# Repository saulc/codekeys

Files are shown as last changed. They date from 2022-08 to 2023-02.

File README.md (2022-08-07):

# codekeys
 arduino based mini mech keyboard

<br />This work is licensed under a <a rel="license" href="http://creativecommons.org/licenses/by-nc-sa/4.0/">Creative Commons Attribution-NonCommercial-ShareAlike 4.0 International License</a>.

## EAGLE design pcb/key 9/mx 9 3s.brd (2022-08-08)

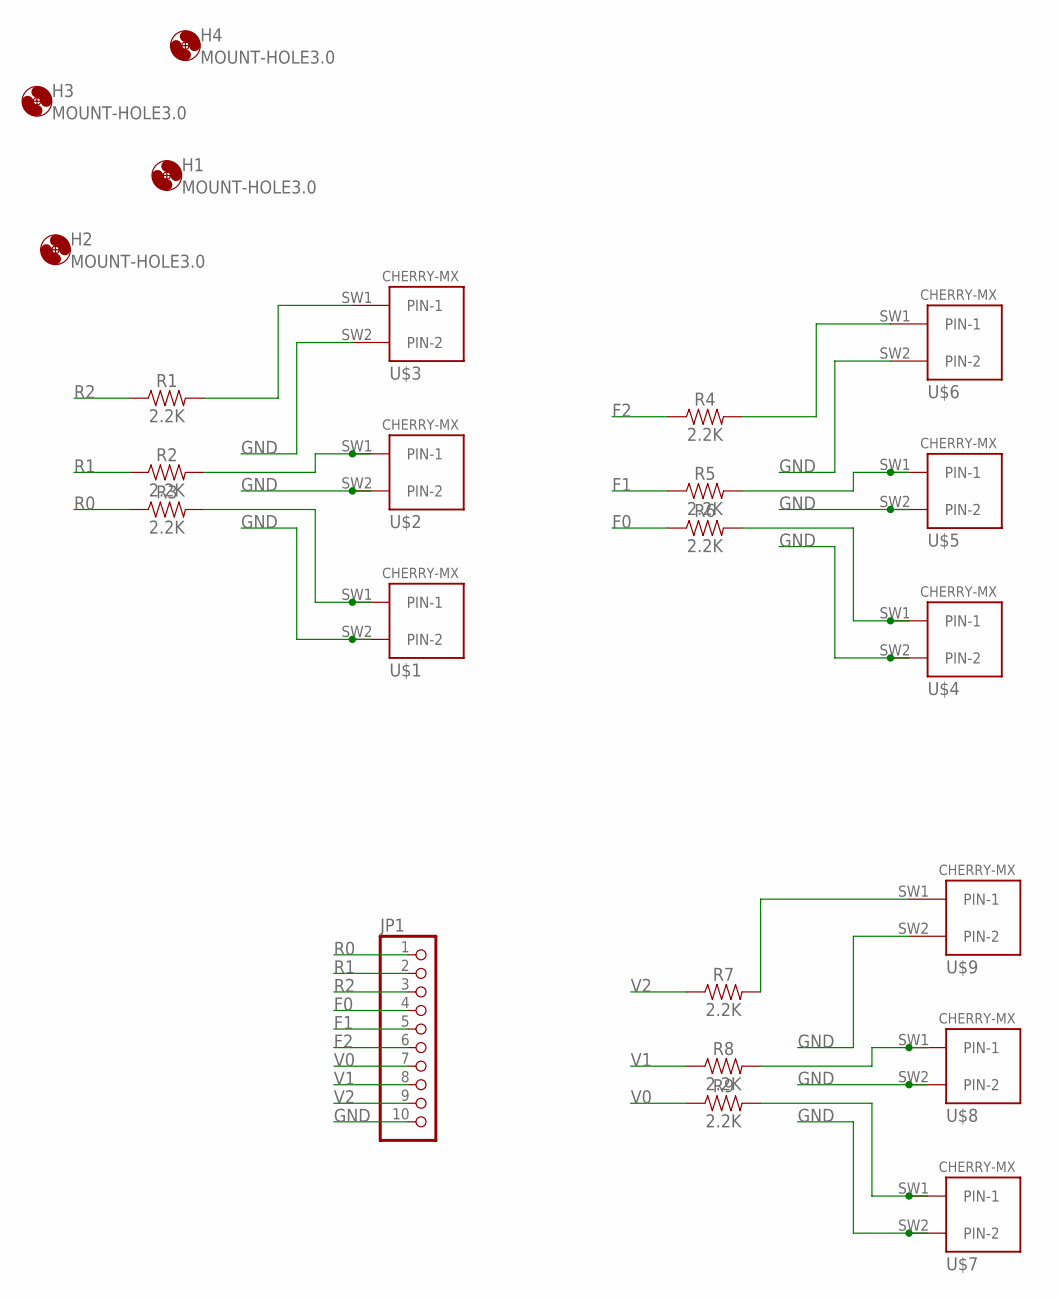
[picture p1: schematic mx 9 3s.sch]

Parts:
H1, H2, H3, H4: MOUNT-HOLE3.0; 3,0
JP1: PINHD-1X10; 1X10
R1, R2, R3, R4, R5, R6, R7, R8, R9: 2.2K; 0402
U$1, U$2, U$3, U$4, U$5, U$6, U$7, U$8, U$9: CHERRY-MX

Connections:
F0: JP1.4, R6.1
F1: JP1.5, R5.1
F2: JP1.6, R4.1
GND: JP1.10, U$1.SW2 (PIN-2), U$2.SW2 (PIN-2), U$3.SW2 (PIN-2), U$4.SW2 (PIN-2), U$5.SW2 (PIN-2), U$6.SW2 (PIN-2), U$7.SW2 (PIN-2), U$8.SW2 (PIN-2), U$9.SW2 (PIN-2)
K0: R3.2, U$1.SW1 (PIN-1)
K1: R2.2, U$2.SW1 (PIN-1)
K2: R1.2, U$3.SW1 (PIN-1)
K3: R4.2, U$6.SW1 (PIN-1)
K4: R5.2, U$5.SW1 (PIN-1)
K5: R6.2, U$4.SW1 (PIN-1)
K6: R7.2, U$9.SW1 (PIN-1)
K7: R8.2, U$8.SW1 (PIN-1)
K8: R9.2, U$7.SW1 (PIN-1)
R0: JP1.1, R3.1
R1: JP1.2, R2.1
R2: JP1.3, R1.1
V0: JP1.7, R9.1
V1: JP1.8, R8.1
V2: JP1.9, R7.1

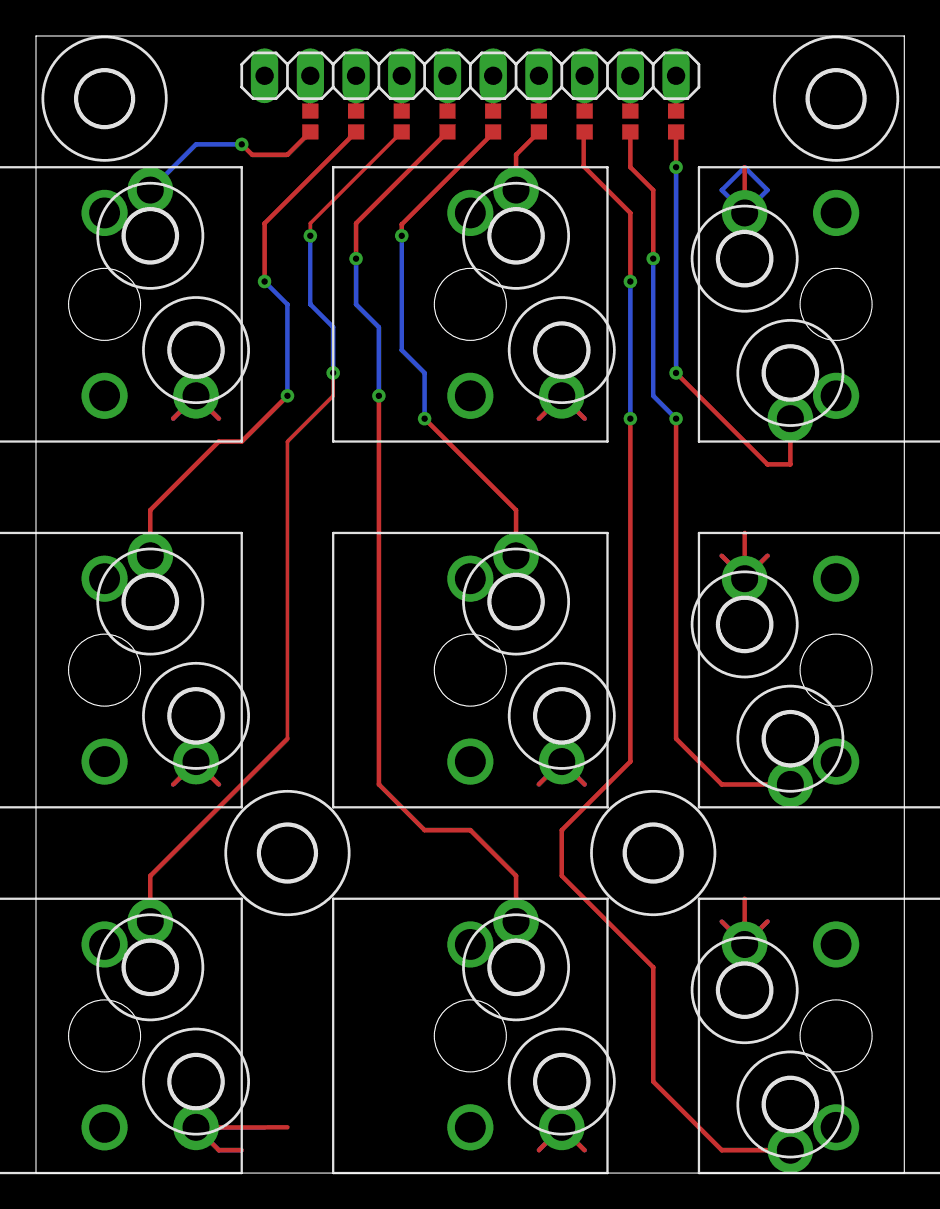
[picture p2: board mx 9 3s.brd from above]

Board: 2 copper layers, 48.2 x 63.2 mm, 23 parts (0 on the bottom side), 19 nets.

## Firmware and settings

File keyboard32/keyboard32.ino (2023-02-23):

/*
 * Code keys v1 - 2022/8/8 Saul C.
 * 
 * mini keyboard - code keys 3 x 3
  micro based keyboard 3 interupts.  7 pinchange interupt? 6!
  pins: int: 2,3,7 pcint: 8,9,10, 14, 15, 16   
  spaceL  mc  spaceR        macOS
  comment uncomment ([0, 0, 0]) 'custom openscad'
  tab/return  copy/cut  paste/paste+return
  
*/    

//#include "Keyboard.h"
//#include "NeoLite.h"
#include "analog.h"
#include "button.h"
#include <BleKeyboard.h>
#include "WiFi.h"
#include "driver/adc.h"

analog batt(BATT_MONITOR);

BleKeyboard bleKeyboard("Acme3x3Keybored");

//NeoLite rgb(PIN_NEOPIXEL, 1); //PIN_NEOPIXEL
 
/*   
 *    Don't Change These after pcb setup.
 */
const int pins[9] = {   21, 12, 27, 
                        33, 15, 32, 
                        14, 25,  26   };
                       
//hardware interupts
Button a( pins[0] );
Button b( pins[1] );
Button c( pins[2] );
Button a1( pins[3] );
Button a2( pins[4] );
Button a3( pins[5] );
Button b1( pins[6] );
Button b2( pins[7] );
Button b3( pins[8] );
const int d = 11; //release delay

/*   
 *    Edit key actions here.
 */
//interupt callbacks// top row
void IRAM_ATTR aclick(){ 
    int t = a.tap();
    if(t==1) commandKey(1); 
    else if(t >= 2) commandKey(0);
   
}
void IRAM_ATTR bclick(){ 
    int t = b.tap();
    if(t==1)   commandKey(2);
    else  if(t >= 2) dt(1);
     
}    
void IRAM_ATTR cclick(){ 
    int t = c.tap();
    if(t==1) commandKey(6);  //
}   
 
 //pin change interupt callbacks
 //middle row
void IRAM_ATTR one(void){
    int t = a1.tap();
    if(t==1) dt(0);
    else if(t >= 2)  dt(1);
}   
        
void IRAM_ATTR two(void){
    int t = a2.tap();
    if(t>=1) ar(2);  //up
//    else if(t>=2)  for(int i=0; i<4; i++) ar(2);
}
void IRAM_ATTR three(void){
    int t = a3.tap(); 
    if(t==1) dt(2); 
    else if(t >= 2)  dt(3);
}  
//bottom row  fliped
void IRAM_ATTR four(void){
    int t = b1.tap(); 
    if(t==1)  ar(1); //right      
    else if(t >= 2) ar(5);
}
void IRAM_ATTR five(void){
    int t = b2.tap();
    if(t>=1)   ar(3); //down    
//    else if(t>=2)  for(int i=0; i<4; i++) ar(3);
    
} 
void IRAM_ATTR six(void){ 
    int t = b3.tap();
    if(t==1)  ar(0); //left
    else if(t >= 2) ar(4);
}   

void disableWifi(){
        adc_power_off();
    WiFi.disconnect(true);  // Disconnect from the network
    WiFi.mode(WIFI_OFF);    // Switch WiFi off
}

bool checkBattLevel(bool update = false){
  int v = batt.getVal();
  if(update) bleKeyboard.setBatteryLevel(v);
  if(v <= 55) return true; //low battery 
  //if(v < 44)  //enable sleep mode
  return false;
}
 
void setup() {  
  setCpuFrequencyMhz(80);
  disableWifi();  //need to reduce program size by 11% wtf...
  checkBattLevel();
//  //turn off the builtin led
  pinMode(13, OUTPUT);
  digitalWrite(13, HIGH);
//  pinMode(NEOPIXEL_I2C_POWER, OUTPUT);
//  digitalWrite(NEOPIXEL_I2C_POWER, HIGH);
//    rgb.ini();
//    rgb.setStyle(1);
//    rgb.setPower(50);
  
   //initialize interupts for buttons
   a.ini();
   attachInterrupt(a.getPin(), aclick, FALLING ); 
   b.ini();
   attachInterrupt(b.getPin(), bclick, FALLING ); 
   c.ini();
   attachInterrupt(c.getPin(), cclick, FALLING ); 
   a1.ini();
   attachInterrupt(a1.getPin(), one, FALLING ); 
   a2.ini();
   attachInterrupt(a2.getPin(), two, FALLING ); 
   a3.ini();
   attachInterrupt(a3.getPin(), three, FALLING ); 
   b1.ini();
   attachInterrupt(b1.getPin(), four, FALLING ); 
   b2.ini();
   attachInterrupt(b2.getPin(), five, FALLING ); 
   b3.ini();
   attachInterrupt(b3.getPin(), six, FALLING ); 
   
  // initialize control over the keyboard:
//  Keyboard.begin();
  checkBattLevel();
  Serial.begin(115200);
  Serial.println(F("Acme Ble Keys"));
  Serial.println(F("Starting BLE work!"));
  bleKeyboard.begin();  
  checkBattLevel();
  checkBattLevel(true); //update and show avg battery level
}
void showCon(){
    Serial.print(F("3x3 Keybored("));
    Serial.print(batt.getVal());
    Serial.println(F("%) is Connected ..."));
}
  bool lowBatt = false;
  int t = 0, tt = 0;
  volatile int mm = 0; //key pressed flag
void loop() {  
//      if(t%10000 == 0) rgb.tik();
//  RGB control goes here lol
  if(t++ >100000){      //don't flood the console, esp32 is fast...
       t = 0;
       tt++;
      if(bleKeyboard.isConnected()) showCon();
//      rgb.setStyle(2);
      if(!lowBatt) digitalWrite(13, LOW); //keep the light on if the battery is low
  }
  if(tt > 2 and mm !=0){
//    Serial.println("  key tapped...");
      lowBatt = checkBattLevel(true);  
 //updated the battery level if the user tapped a button. (don't wake from sleep)
       mm = 0;
       tt = 0;
//       rgb.setStyle(1);
      digitalWrite(13, HIGH); //keypress indicator
  }
}
/* 
 * ----------------Short cuts --------------------
 */
void commandKey(int a){
  
  char c = 'x';
    switch(a){
      case 0: c = 'x';
        break;
      case 1: c = 'c';
        break;
      case 2: c = 'v';
        break;
        case 3: c = 'd';
        break; 
        case 4: c = 'd';    
        bleKeyboard.press(KEY_RIGHT_SHIFT); 
        break;
        case 5: c = '/';
        break;
        case 6: c = 'z';
        break;  
        
    }     
    
//    bleKeyboard.press(KEY_LEFT_CTRL);  // press and hold control windoz
//    bleKeyboard.press(KEY_RIGHT_SHIFT);  //  hold Shift for testing!! 
    bleKeyboard.press(KEY_LEFT_GUI);  // press and hold command macOS not X
    bleKeyboard.press(c);          
        kbrelease();  
         mm++; //key pressed flag
}
//change spaces/destops
void spaceL(){ space(0); }
void spaceR(){ space(1); }
void space(int d){   
  //ctrl shift tab /ctrl tab  - switch chrome tabs left right 
    bleKeyboard.press(KEY_LEFT_CTRL);  // press and hold control windoz 
    if(d==2) bleKeyboard.press(KEY_UP_ARROW);   //spaces/mission control
    else    bleKeyboard.press( (d==0) ? KEY_LEFT_ARROW : KEY_RIGHT_ARROW);      
    
    kbrelease();  
     mm++;
}
void ar(int a){
  
  char c = 'a'; 
  switch(a){
    case 0: c = KEY_LEFT_ARROW; break;   
    case 1: c = KEY_RIGHT_ARROW; break;
    case 2: c = KEY_UP_ARROW; break;
    case 3: c = KEY_DOWN_ARROW; break;
    case 4: c = KEY_LEFT_ARROW; 
              bleKeyboard.press(KEY_LEFT_ALT);
              break;
    case 5: c = KEY_RIGHT_ARROW; 
              bleKeyboard.press(KEY_LEFT_ALT);
              break;
  }
  bleKeyboard.press(c);      
  bleKeyboard.release(c);   
  if(a >= 4)  bleKeyboard.release(KEY_LEFT_ALT);
//  kbrelease();
   mm++;
}
 //single key shortcuts
void dt(int a){  
    int k = 0;
    switch(a){
      case 0: k = KEY_TAB;    break;
      case 1: k = KEY_RETURN;  break;
      case 3: bleKeyboard.press(KEY_LEFT_ALT);
      case 2: k = KEY_BACKSPACE;  break;

    }
      bleKeyboard.press(k); 
      bleKeyboard.release(k);   
      if(a > 2)  bleKeyboard.release(KEY_LEFT_ALT);
    mm++;
} 


/* 
 * ----------------end Short cuts --------------------
 */     
 
//write keystrokes or just use print
void macro(String s){
  for(int i=0; i<s.length(); i++)
           bleKeyboard.write(s[i]); 
}
void kbrelease(){
    delay(d);  //fixes command click after wake.!
    bleKeyboard.releaseAll(); 
}

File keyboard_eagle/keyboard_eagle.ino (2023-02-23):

/*
 * Code keys v1 - 2022/8/8 Saul C.
 * 
 * mini keyboard - code keys 3 x 3
  micro based keyboard 3 interupts.  7 pinchange interupt? 6!
  pins: int: 2,3,7 pcint: 8,9,10, 14, 15, 16   
 
    custom Eagle PCB Cad layout
    move     undo     redo
    rotate   text     delete
    wire    rip       rn
    

*/    

#include "Keyboard.h"
#include "button.h"
 void one();
 void two();
 void three();
 void four();
 void five();
 void six(); 
 void cclick();
 void aclick();
 void bclick(); 

const int pins[9] = {   2,  3,   7 , 
                        8,  9,   10, 
                        14, 15,  16   };
             


// pin change interups
Button a1( pins[3] , one, false);
Button a2( pins[4] , two, false);
Button a3( pins[5] , three, false);
Button b1( pins[6] , four, false);
Button b2( pins[7] , five, false);
Button b3( pins[8] , six, false);
//hardware interupts
Button a( pins[0] , aclick, true);
Button b( pins[1] , bclick, true);
Button c( pins[2] , cclick, true);

const int d = 11; //release delay
//interupt callbacks
void aclick(){ 
    int t = a.tap();
    if(t==1)  macro("1");      
    else if(t == 2) macro("rule #2");
}
void bclick(){ 
    int t = b.tap();
    if(t==1)  macro("2");
}    
void cclick(){ 
    int t = c.tap();
    if(t==1)  macro("3");
}   
 
 //pin change interupt callbacks
void one(void){
    int t = a1.tap();
    if(t==1) macro("4");
}   
        
void two(void){
    int t = a2.tap();
      if(t==1)   macro("5");
}
void three(void){
    int t = a3.tap();
    if(t==1) macro("6");
}  
//top row   

void four(void){
    int t = b1.tap();
    if(t==1) macro("7");
     
}
void five(void){
    int t = b2.tap();
    if(t==1) macro("8");
    
} 
void six(void){ 
    int t = b3.tap();
    if(t==1) macro("9");
}   

void setup() { 
  //turn off the builtin led
  pinMode(13, OUTPUT);
  digitalWrite(13, LOW);
   //initialize interupts for buttons
   a.ini();  
   b.ini(); 
   c.ini(); 
   a1.ini();
   a2.ini();
   a3.ini();
   b1.ini();
   b2.ini();
   b3.ini();
  // initialize control over the keyboard:
  Keyboard.begin();
}
 
//    move     undo     redo
//    rotate   text     delete 
//    wire    rip       rn
void ee(int a){
  char c = 'a'; 
  switch(a){
    case 0: c = 'm'; break;  //move
    case 1: c = 'z'; break; //undo
    case 2: c = 'y'; break; //redo
    case 3: c = 'b'; break; //rotate
    case 4: c = 't'; break;  //text
    case 5: c = 'd'; break;  //delete
    case 6: c = '1'; break;   //route wire
    case 7: c = 'r';          //ripup
           Keyboard.press(KEY_LEFT_SHIFT); 
           break;
    case 8: c = 'n'; break; //ratsnest
  }
  Keyboard.press(KEY_LEFT_CTRL);
  Keyboard.press(c);
  kbrelease();
  
}

void loop() {  
//  RGB control goes here lol
} 
void ar(int a){
  char c = 'a'; 
  switch(a){
    case 0: c = KEY_LEFT_ARROW; break;   
    case 1: c = KEY_RIGHT_ARROW; break;
    case 2: c = KEY_UP_ARROW; break;
    case 3: c = KEY_DOWN_ARROW; break;
    case 4: c = KEY_LEFT_ARROW; 
              Keyboard.press(KEY_LEFT_ALT);
              break;
    case 5: c = KEY_RIGHT_ARROW; 
              Keyboard.press(KEY_LEFT_ALT);
              break;
  }
  Keyboard.press(c);
  kbrelease();
  
}
 //single key shortcuts
void dt(int a){  
    if(a == 0) Keyboard.press(KEY_TAB); 
    else if(a == 1) Keyboard.press(KEY_RETURN);  
    else if(a >= 2)   {
      if(a == 3) Keyboard.press(KEY_LEFT_ALT);
      Keyboard.press(KEY_BACKSPACE); 
    }
    kbrelease();
} 
/* 
 * ----------------end Short cuts --------------------
 */     


 
//write keystrokes 
void macro(String s){
  for(int i=0; i<s.length(); i++)
           Keyboard.write(s[i]); 
}
void kbrelease(){
    delay(d);  //fixes command click after wake.!
    Keyboard.releaseAll(); 
}

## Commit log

2022-08-04 difference short cuts
    is 3 keys enough?
    [button.h, keyboardMicro3.ino]
2022-08-05 3x3
    i guess 10x keys is possible?
    adding pcint buttons
2022-08-05 9 buttons!
    micro doesn't have a pin 11. or 12..
    [button.h, keyboardMicro3.ino]
2022-08-07 name change
    mode switch could be interesting...
2022-08-08 added eagle files
    3x3 v1
    [mx 9 3s.brd, mx 9 3s.sch]
2022-08-10 base code
    for software rotate/transpose.
    rotate layout quickly.
    account for alt wiring.
2022-08-31 wireless
    esp32 v2 feather working with ble keyboard fully wireless....
    needs indicators. led/rgb...
    external reset button? or a hole...
2022-08-31 battery level
    and fixed crash(blocking) issue...
    [keyboard32.ino]
2022-08-31 batt level
    added analog smoothing to batt level and 'active' mode updates.
    fixed sleep/wake issue.?
    [keyboard32.ino]
2023-02-23 batt
    wireless

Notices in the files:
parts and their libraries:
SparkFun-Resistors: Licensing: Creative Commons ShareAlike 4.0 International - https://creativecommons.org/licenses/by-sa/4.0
